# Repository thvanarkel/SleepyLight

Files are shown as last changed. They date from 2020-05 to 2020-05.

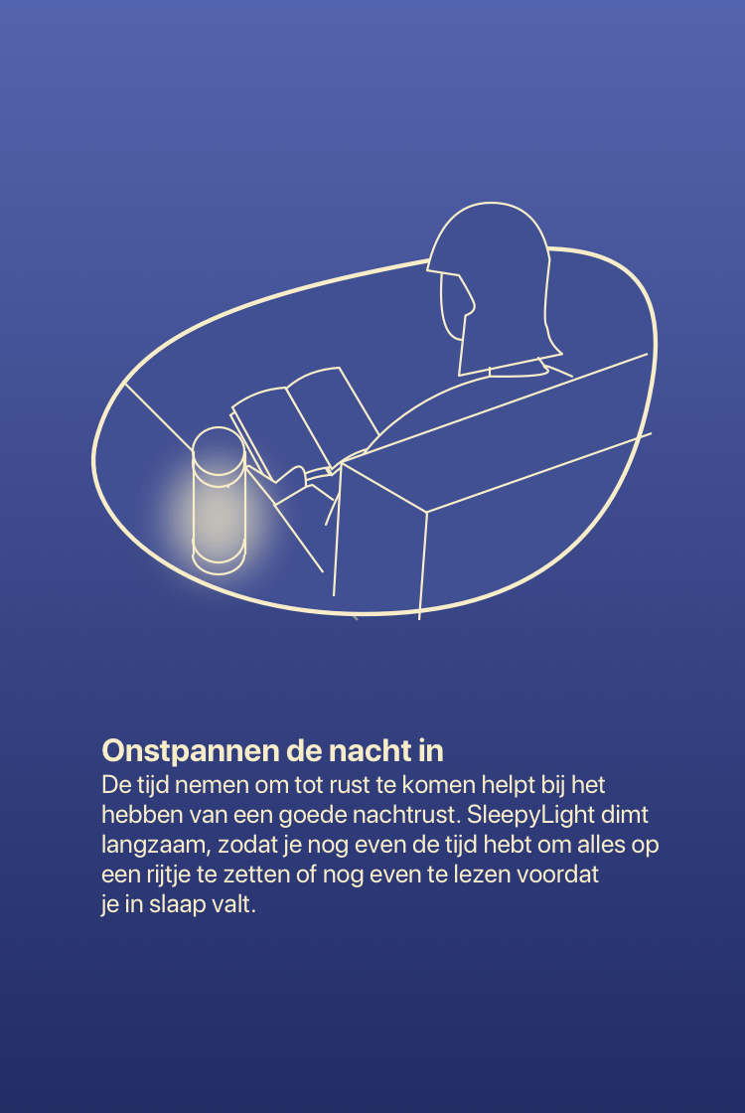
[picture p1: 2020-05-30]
Software/sleepy-config/src/images/flow03.png

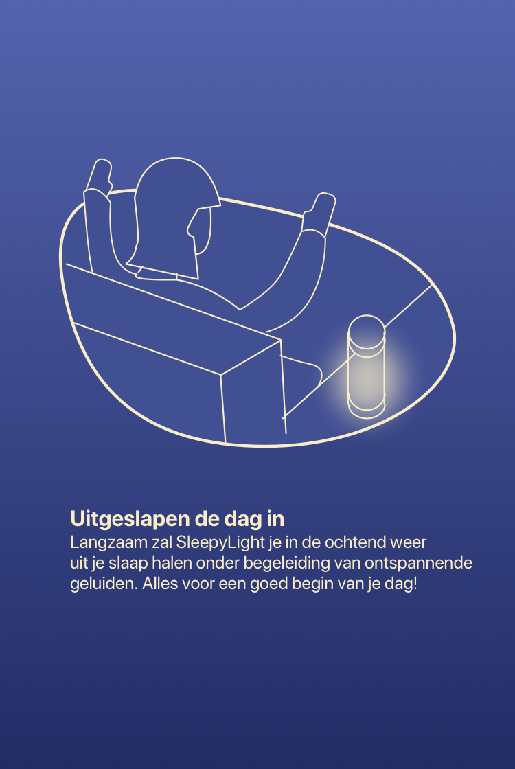
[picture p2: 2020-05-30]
Software/sleepy-config/src/images/flow04.png

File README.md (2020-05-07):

# SleepyLight
Prototype of an interactive SleepyLight. Designed and built for use in the [data-informed-design-experiments](https://github.com/thvanarkel/data-informed-design-experiments) study.

## How to build your own
1. ...
x. Add an arduino_secrets.h file with the following template

```
#define SECRET_SSID ""
#define SECRET_PASS ""
```

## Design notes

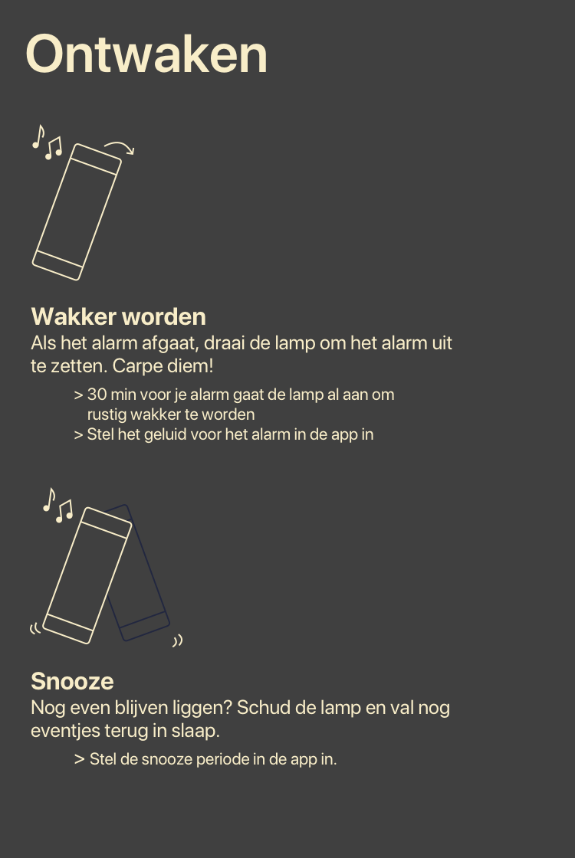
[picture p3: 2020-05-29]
Software/sleepy-config/src/images/help03.png

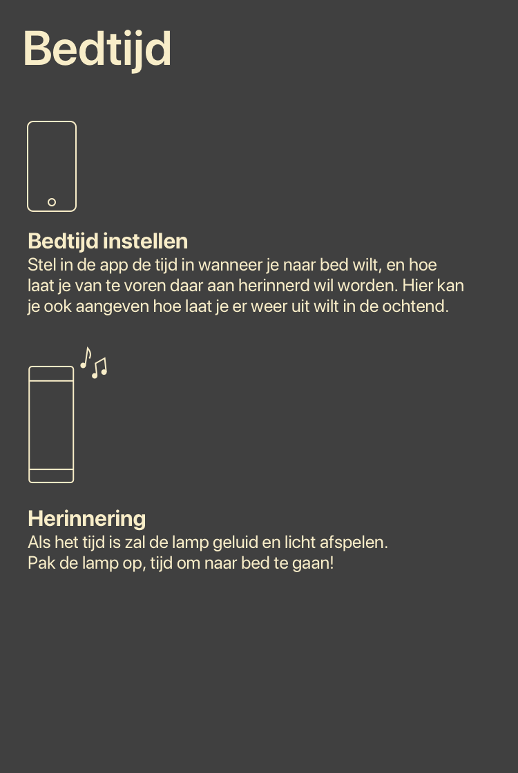
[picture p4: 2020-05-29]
Software/sleepy-config/src/images/help01.png

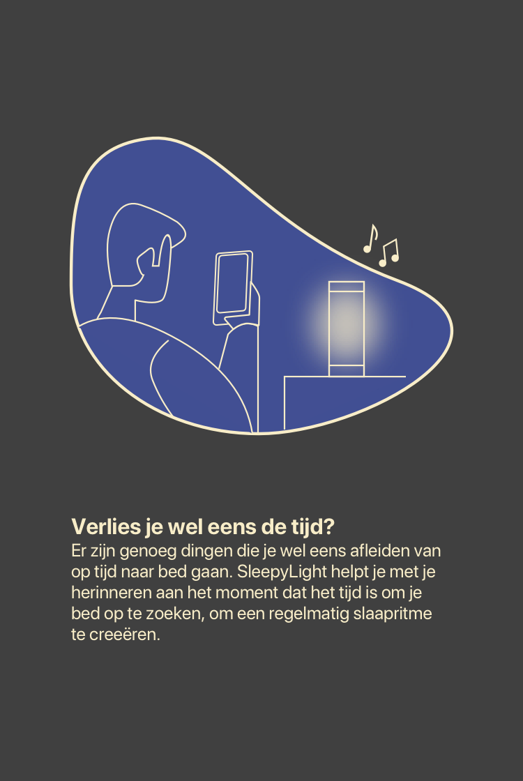
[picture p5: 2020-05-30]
Software/sleepy-config/src/images/flow02.png

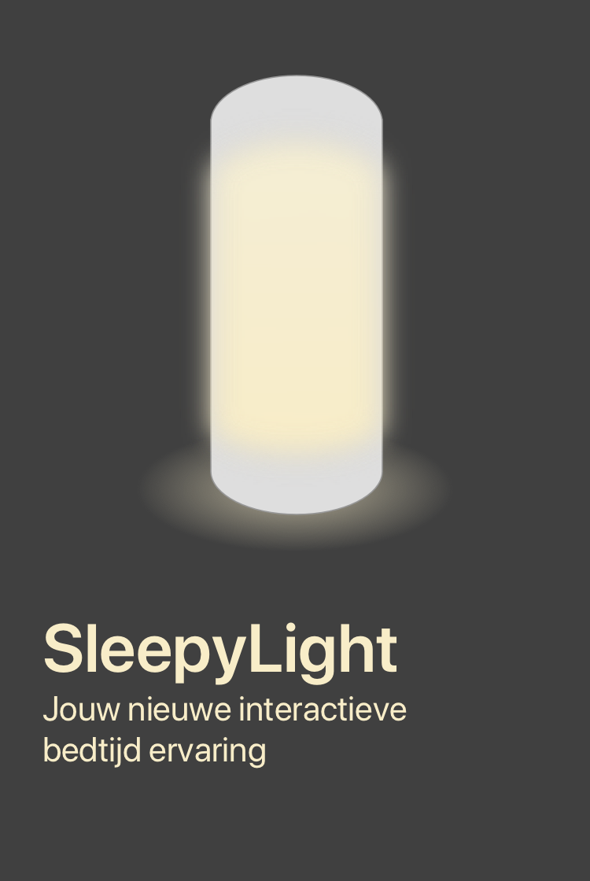
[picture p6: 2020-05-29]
Software/sleepy-config/src/images/flow01.png

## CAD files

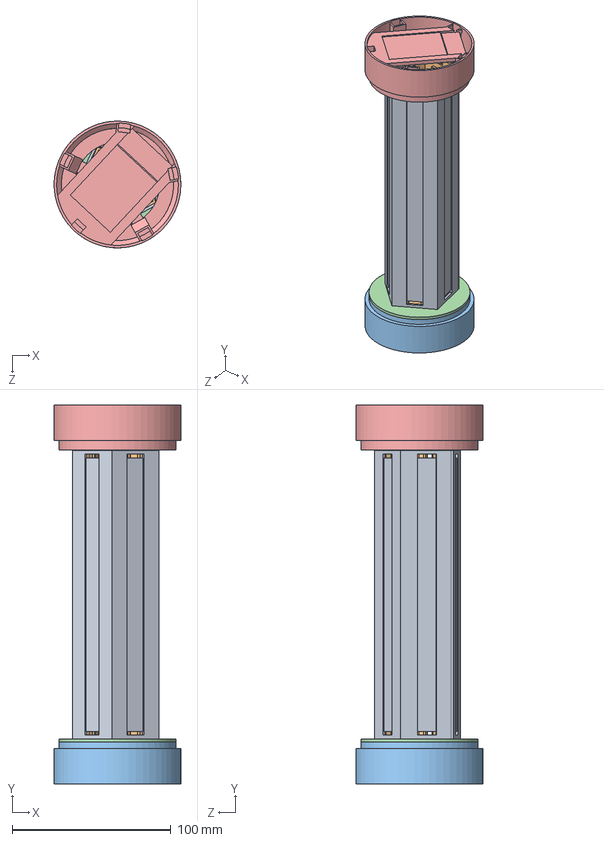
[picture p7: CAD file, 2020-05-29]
Hardware/Lamp.SLDASM
80.0 x 239.0 x 80.0 mm
LED ring
Core
Base
Core connector
Top

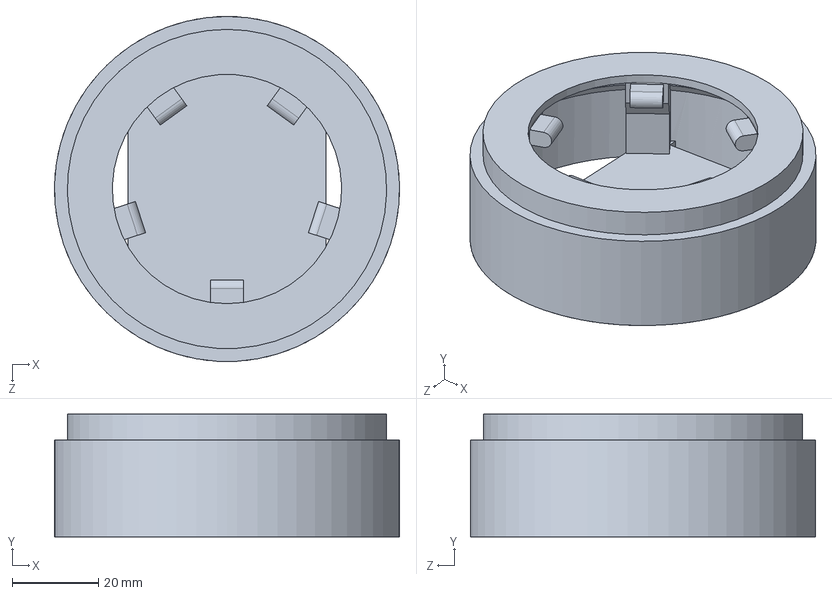
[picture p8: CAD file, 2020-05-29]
Hardware/Top.SLDPRT
80.0 x 28.5 x 80.0 mm

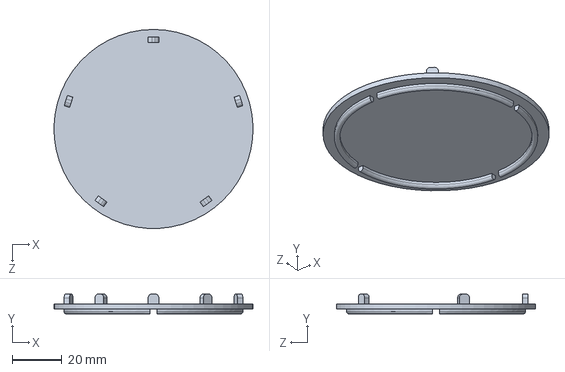
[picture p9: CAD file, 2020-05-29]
Hardware/Top Cap.SLDPRT
80.0 x 8.00 x 80.0 mm

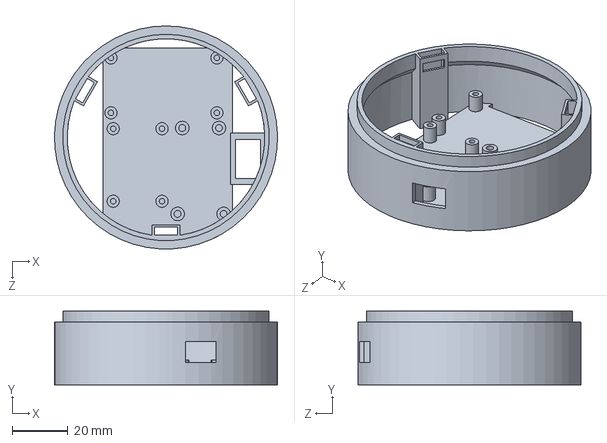
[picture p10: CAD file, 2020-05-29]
Hardware/Base power hole.SLDPRT
80.0 x 26.5 x 80.0 mm

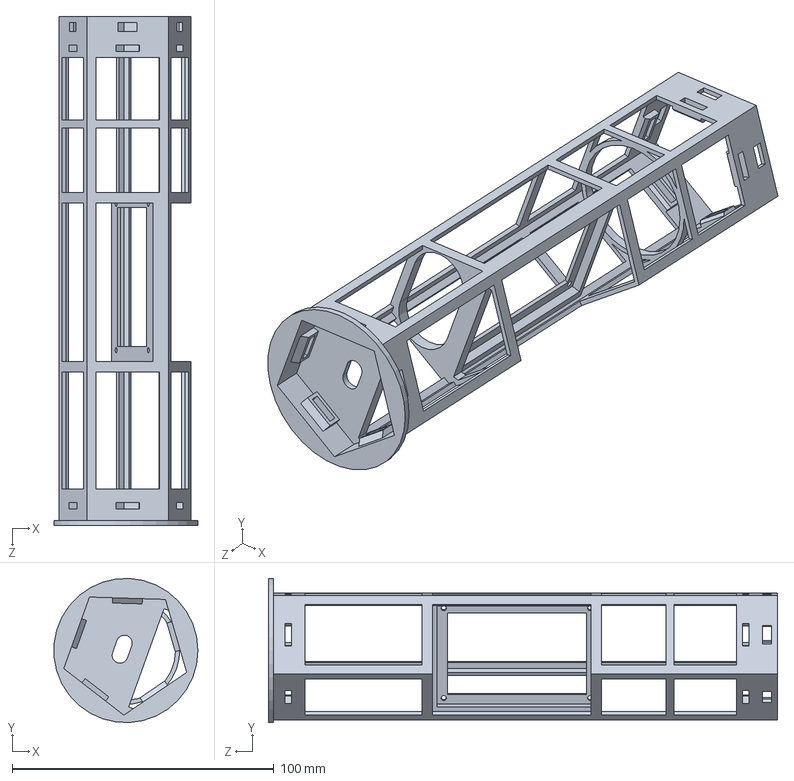
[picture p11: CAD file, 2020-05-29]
Hardware/Core.SLDPRT
55.0 x 55.1 x 194.6 mm

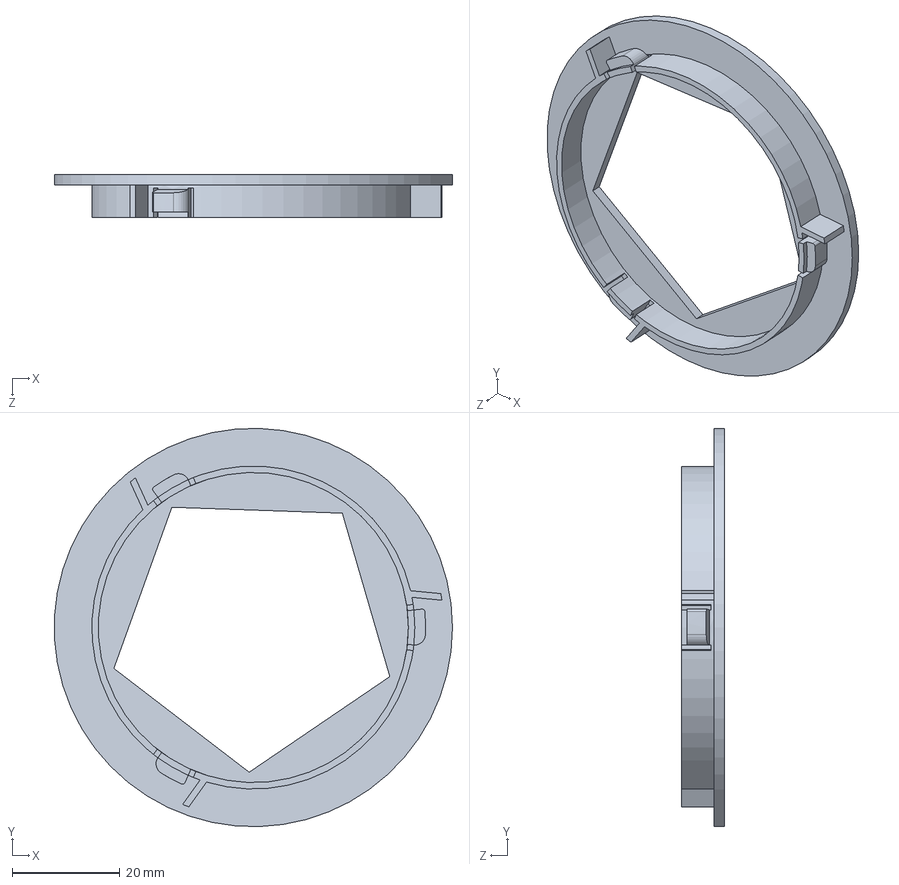
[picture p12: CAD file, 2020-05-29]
Hardware/Core connector.SLDPRT
73.9 x 74.0 x 8.00 mm

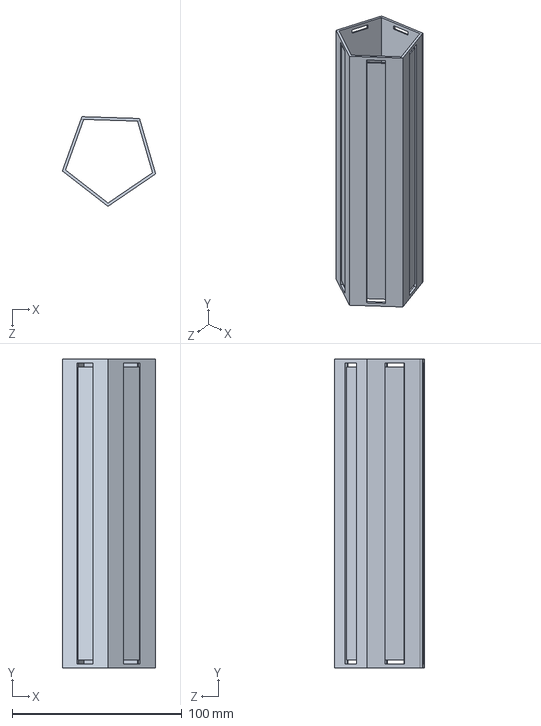
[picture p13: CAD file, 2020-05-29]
Hardware/LED ring.SLDPRT
55.0 x 182.0 x 52.8 mm

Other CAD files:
Hardware/Cap.SLDPRT
Hardware/Base.SLDPRT
Hardware/Base power hole.STL
Hardware/Base.STL
Hardware/Cap.STL
Hardware/Core connector.STL
Hardware/Core.STL
Hardware/LED ring.STL
Hardware/Top Cap.STL
Hardware/Top.STL

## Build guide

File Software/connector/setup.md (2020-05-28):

# Setup

## Requirements
- Raspberry Pi (+ SD card) with Raspbian installed
- USB drive (formatted in exFAT, named 'collector##')

## a. Configuration
1. Flash the SD card with the latest version of Raspbian (through for instance Etcher)
2. Setup the Raspberry Pi (language/timezone/password/update etc.)
3. Change hostname (in RPi Configuration > System) to 'collector##'
4. Enable SSH mode (in RPi Configuration > Interfaces)
5. Update Nodejs
```
$ sudo su
$ curl -sL https://deb.nodesource.com/setup_13.x | bash -
$ apt-get install -y nodejs
```
6. Install exFAT utils
```
$ sudo apt-get install exfat-fuse exfat-utils
```
7. Insert the USB stick (formatted in exFAT, named the same as in step 3: 'collector##')

## b. MQTT server
8. Install Mosquitto
```
$ sudo apt install -y mosquitto mosquitto-clients
$ sudo systemctl enable mosquitto.service
```
9. Configure the mosquitto broker by adding the following to `/etc/mosquitto/conf.d/mosquitto.conf`
```
password_file /etc/mosquitto/passwd
allow_anonymous false
```
10. Add the password file
`$ sudo mosquitto_passwd -c /etc/mosquitto/passwd <user_name>`
11. Restart the mosquitto broker
`$ sudo systemctl restart mosquitto`

## c. Collector script
12. Clone the repository
```
$ git clone https://github.com/thvanarkel/data-informed-design-experiments
```
13. Change to the collector directory, install and add the `.env` file
```
$ cd data-informed-design-experiments/collector
$ npm install
$ touch .env
$ nano .env
```
and add the following:
```
USERN={broker-username}
PASSWORD={broker-password}
HOST={InfluxDB-host-url}
TOKEN={InfluxDB-token}
ORG={InfluxDB-organisation}
BUCKET={InfluxDB-bucket-name}
```
14. Install pm2 and run the collector script on startup
```
$ sudo npm install -g pm2
$ cd /home/pi/Documents/data-informed-design-experiments/collector
$ pm2 start collector.js
$ pm2 startup
$ pm2 save
```

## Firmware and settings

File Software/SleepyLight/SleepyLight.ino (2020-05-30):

#include <WiFiNINA.h>
#include <ArduinoOTA.h>
#include "Lamp.h"
#include <MQTT.h>
#include <SD.h>
#include <SDConfigCommand.h>
#include <ArduinoSound.h>
#include <Arduino_LSM6DS3.h>
#include "SensorFusion.h"

#include <Wire.h>
#include "ds3231.h"
#include "RTClib.h"

#include "arduino_secrets.h">
char ssid[] = SECRET_SSID;
char pass[] = SECRET_PASS;

int status = WL_IDLE_STATUS;

#define LED_TYPE WS2812
#define DATA_PIN 6
#define NUM_LEDS 50

bool turnedOn = false;

WiFiClient net;
MQTTClient client;

RTC_DS3231 rtc;

//char bedtimeDays[8] = "0111110";
//char wakeupDays[8] = "0111110";
//String bedtimeAlarm;
//String wakeupAlarm;

Lamp lamp(5, 10);
unsigned long lastUpdate;

uint8_t sleep_period = 1;
unsigned long prev = 5000, interval = 1000;


struct Config {
  String key;
  String value;
};


#define NUM_CONFIGS 10

Config defaultConfig[NUM_CONFIGS] = {
  {"bedtimedays", "000000"},
  {"wakeupdays", "000000"},
  {"wakeupalarm", "8:00:00"},
  {"bedtimealarm", "23:00:00"},
  {"awakeningtime", "30"},
  {"unwinddecay", "30"},
  {"slumberdecay", "30"},
  {"snooze", "8"},
  {"currentsound", "3"},
  {"bedtimereminder", "30"}
};

Config configuration[NUM_CONFIGS] = {
  {"bedtimedays", ""},
  {"wakeupdays", ""},
  {"wakeupalarm", ""},
  {"bedtimealarm", ""},
  {"awakeningtime", ""},
  {"unwinddecay", ""},
  {"slumberdecay", ""},
  {"snooze", ""},
  {"currentsound", ""},
  {"bedtimereminder", ""}
};


// State parameters

int slumberIntensity = 65;
//int slumberDecay = 30 * 1000;
int slumberShake = 2500;

//int awakeningPeriod = 1; // in minutes

//int unwindDecay = 30;

//int snoozePeriod = 8; // in minutes


#define SHUTDOWN_PIN 5

struct Sound {
  char filename[14];
  int duration;
};

static Sound sounds[8] = {{"birdsong.wav", 61},
  {"bright.wav", 61},
  {"droplets.wav", 61},
  {"early.wav", 54},
  {"helios.wav", 64},
  {"orbit.wav", 64},
  {"spring.wav", 70},
  {"sunny.wav", 60}
};

int currentSound;
unsigned long startedPlaying;

SDConfigCommand sdcc;
SDWaveFile waveFile;

unsigned long reminded;

Orientation orientation;
Orientation lOrientation;
boolean didTurn;
int nShakes;

enum Movement {
  PICKUP = 0,
  SHAKE = 1,
  TURN = 2
};

enum State {
  LIGHT_IDLE,
  REMINDING,
  UNWINDING,
  SLUMBERING,
  AWAKENING,
  ALARMED
};

State currentState = LIGHT_IDLE;
State lastState;

void setup() {
  // put your setup code here, to run once:
  //  Serial.begin(115200);
  //  Serial.print("connecting");
  while (status != WL_CONNECTED) {
    // Connect to WPA/WPA2 network. Change this line if using open or WEP network:
    status = WiFi.begin(ssid, pass);

    // wait 10 seconds for connection:
    Serial.print(".");
    delay(1000);
  }
  client.begin("broker.shiftr.io", net);
  client.onMessage(messageReceived);
  connect();

  client.publish("/restart", "1");


  // Initialise SD card reader and I2S speaker
  if (!SD.begin()) {
    client.publish("/error", "SD initialization failed");
    //    return;
  }

//  SD.remove("setting.cfg"); // Delete configuration file
  // check config
  loadConfig();

  // Initialise RTC
  Wire.begin();
  if (!rtc.begin()) {
    client.publish("/error", "Couldn't find RTC");
  }
  if (rtc.lostPower()) {
    client.publish("/error", "RTC lost power, let's set the time!");
    rtc.adjust(DateTime(F(__DATE__), F(__TIME__)));
  }

  setAlarm(getConfig("wakeupalarm"), true);
  setAlarm(getConfig("bedtimealarm"), false);

  currentSound = getConfig("currentsound").toInt();
  waveFile = SDWaveFile(sounds[currentSound].filename);
  if (!waveFile) {
    client.publish("/error", "wave file invalid");
  }
  AudioOutI2S.volume(60);
  if (!AudioOutI2S.canPlay(waveFile)) {
    client.publish("/error", "unable to play wave file using I2S!");
  }

  // Initialise shutdown pin speaker
  pinMode(SHUTDOWN_PIN, OUTPUT);
  digitalWrite(SHUTDOWN_PIN, LOW);

  if (!IMU.begin()) {
    Serial.println("Failed to initialize IMU!");
  }

  ArduinoOTA.begin(WiFi.localIP(), "SleepyLight", OTA_PASSWORD, InternalStorage);

  updateOrientation();
  // set the initial orientation
  orientation = getOrientation();
  lamp.orientation = orientation;
  client.publish("/orientation", String(orientation));

  client.publish("/state", String(currentState));
  lastState = currentState;
}


int cIndex = 0;

void loadConfig() {
  Serial.println("Creating example.txt...");

  File myFile;

  if (!SD.exists("setting.cfg")) {
    Serial.println("file does not exist");
    myFile = SD.open("setting.cfg", FILE_WRITE);
    writeDefaultConfig(myFile);
    myFile.close();
  }
  // Load the configuration
  while ( !(sdcc.set("setting.cfg", 4, processCmd)) ) {}

  sdcc.readConfig();

}

void writeDefaultConfig(File file) {
  for (int i = 0; i < NUM_CONFIGS; i++) {
    Config c = defaultConfig[i];
    file.print(c.key);
    file.print("=");
    file.println(c.value);
  }
}

void setConfig(String key, String value) {
  for (int i = 0; i < NUM_CONFIGS; i++) {
    Config c = configuration[i];
    if (c.key.equals(key)) {
      c.value = value;
      configuration[i] = c;
      sdcc.writeConfig(key, value);
    }
  }
}

String getConfig(String key) {
  Serial.println(key);
  for (int i = 0; i < NUM_CONFIGS; i++) {
    Config c = configuration[i];
    if (c.key.equals(key)) {
      return c.value;
    }
  }
}

void processCmd() {
  // This function will run every time there is a command
  // Maybe check the key?
  String k = sdcc.getCmdS();
  String v = sdcc.getValueS();

  if (cIndex < NUM_CONFIGS) {
    configuration[cIndex].key = k;
    configuration[cIndex].value = v;
    cIndex++;
  }

}


void connect() {
  Serial.print("checking wifi...");
  while (WiFi.status() != WL_CONNECTED) {
    status = WiFi.begin(ssid, pass);
    Serial.print(".");
    delay(1000);
  }
  Serial.print("\nconnecting...");
  while (!client.connect("SleepyLight", USERNAME, PASSWORD)) {
    Serial.print(".");
    delay(1000);
  }
  Serial.println("\nconnected!");

  client.subscribe("/turnedOn");
  client.subscribe("/wakeup/#");
  client.subscribe("/bedtime/#");
  client.subscribe("/awakeTime");
  client.subscribe("/unwindTime");
  client.subscribe("/slumberTime");
  client.subscribe("/sound");
  client.subscribe("/snooze");
  //  client.subscribe("/ledLevel");
}

boolean disconnected = false;

void loop() {
  //  watchdog.clear();
  ArduinoOTA.poll();
  lamp.tick();
  //  Serial.println(lamp.level);

  if (!client.connected()) {
    connect();
  }
  client.loop();


  if (!AudioOutI2S.isPlaying()) {
    // playback has stopped
    digitalWrite(SHUTDOWN_PIN, LOW);
    // Doing this during I2S outputting sound willl drop connection
  }

  if (currentState != lastState) {
    client.publish("/state", String(currentState));
    lastState = currentState;
  }
  if (orientation != lOrientation) {
    client.publish("/orientation", String(orientation));
    lOrientation = orientation;
  }

  if (millis() - lastUpdate > 1000) {
    client.publish("/ledLevel", String(lamp.level));
    lastUpdate = millis();
  }

  updateOrientation();
  detectMovement();
  lamp.orientation = orientation;

  //  unsigned long n = millis();
  //  if ((n - prev > interval)) {
  //    DateTime now = rtc.now();
  //    publishDate("/time", now);
  //    prev = n;
  //  }

  updateStateMachine();

  delay(15);
}

void updateStateMachine() {
  switch (currentState) {
    case LIGHT_IDLE:

      // Check if the lamp is turned
      if (detectTurn(orientation)) {
        lamp.orientation = orientation;
        lamp.turnOn(2000);
        currentState = UNWINDING;
      }

      // Check if the wake-up alarm has fired
      if (rtc.alarmFired(1)) {
        rtc.clearAlarm(1);
        DateTime now = rtc.now();
        DateTime future(now + TimeSpan(0, 0, getConfig("awakeningtime").toInt(), 0));
        rtc.setAlarm1(future, DS3231_A1_Hour);
        lamp.turnOn(getConfig("awakeningtime").toInt() * 60 * 1000);
        currentState = AWAKENING;
      }
      if (rtc.alarmFired(2)) {
        rtc.clearAlarm(2);
        
        setSound(5);
        playSound();
        reminded = millis();
        currentState = REMINDING;
      }

      if (!lamp.inAnimation() && nShakes > 3) {
        lamp.setLevel(slumberIntensity, 1500);
        nShakes = 0;
        currentState = SLUMBERING;
      }

      break;

    case REMINDING:
      lamp.mode = MOVING;
      breakOffSound(8);
      if (nShakes > 0 || millis() - reminded > 60000) {
        lamp.mode = SOLID;
        stopSound();
        currentSound = getConfig("currentsound").toInt();
        currentState = LIGHT_IDLE;
        nextAlarm(false);
      }
      break;

    case UNWINDING:        
      if (!lamp.inAnimation()) {
        if (lamp.level >= 1023) {
          lamp.turnOff(getConfig("unwinddecay").toInt() * 60 * 1000);
        } else if (lamp.level <= 0) {
          currentState = LIGHT_IDLE;
        }
      }
      if (nShakes > 3) {
        nShakes = 0;
        lamp.changeTime((-60 * 1000));
      }
      break;

    case AWAKENING:
      if (rtc.alarmFired(1)) {
        rtc.clearAlarm(1);
        playSound();
        nShakes = 0;
        currentState = ALARMED;
      }
      break;

    case ALARMED:
      if (!AudioOutI2S.isPlaying()) {
        // playback has stopped
        playSound();
      } else {
        breakOffSound(8);
      }
      if (nShakes > 3) {
        stopSound();
        nShakes = 0;
        DateTime now = rtc.now();
        DateTime future(now + TimeSpan(0, 0, getConfig("snooze").toInt(), 0)); // TODO: fix the times
        rtc.setAlarm1(future, DS3231_A1_Hour);
        currentState = AWAKENING;
        break;
      }
      if (detectTurn(orientation)) {
        stopSound();
        lamp.orientation = orientation;
        lamp.turnOff(2000);
        nextAlarm(true);
        currentState = LIGHT_IDLE;
        nShakes = 0;
        break;
      }
      break;

    case SLUMBERING:
      if (!lamp.inAnimation()) {
        if (lamp.level >= slumberIntensity) {
          lamp.turnOff(getConfig("slumberdecay").toInt() * 1000);
        } else {
          currentState = LIGHT_IDLE;
        }
      }
      if (nShakes > 2) {
        lamp.setLevel(slumberIntensity, 500);
        nShakes = 0;
      }
      if (detectTurn(orientation)) {
        lamp.orientation = orientation;
        lamp.turnOn(2000);
        currentState = UNWINDING;
      }
      break;
  }
}

String getValue(String data, char separator, int index)
{
  int found = 0;
  int strIndex[] = {0, -1};
  int maxIndex = data.length() - 1;

  for (int i = 0; i <= maxIndex && found <= index; i++) {
    if (data.charAt(i) == separator || i == maxIndex) {
      found++;
      strIndex[0] = strIndex[1] + 1;
      strIndex[1] = (i == maxIndex) ? i + 1 : i;
    }
  }
  return found > index ? data.substring(strIndex[0], strIndex[1]) : "";
}

void setAlarm(String str, boolean wakeup) {
  //(year, month, day, hour, minute, second)

  int alarmIndex = wakeup ? 1 : 2;
  rtc.clearAlarm(alarmIndex);
  DateTime now = rtc.now();
  DateTime a(now.year(), now.month(), now.day(), getValue(str, ':', 0).toInt(), getValue(str, ':', 1).toInt(), 0);
  if (now < a) {
    // Still do the alarm today
    char theDay;
    if (wakeup) {
      char wd[8];
      getConfig("wakeupdays").toCharArray(wd, 8);
      theDay = wd[now.dayOfTheWeek()];
    } else {
      char bd[8];
      getConfig("bedtimedays").toCharArray(bd, 8);
      theDay = bd[now.dayOfTheWeek()];
    }
    if (theDay == '1') {
      DateTime future;
      if (wakeup) {
        int o = getConfig("awakeningtime").toInt();
        future = a - TimeSpan(0, 0, o, 0);
        rtc.setAlarm1(future, DS3231_A1_Hour);
        publishDate("/wakeup/date", future);
      } else {
        future = a - TimeSpan(0, 0, getConfig("bedtimereminder").toInt(), 0);
        rtc.setAlarm2(future, DS3231_A2_Hour);
        publishDate("/bedtime/date", future);
      }
    } else {
      nextAlarm(wakeup);
    }
  } else {
    // Schedule next alarm
    nextAlarm(wakeup);
  }
}


void nextAlarm(boolean wakeup)
{
  //  DateTime future(now + TimeSpan(0, 0, 1, 0));
  //
  //  rtc.setAlarm1(future, DS3231_A1_Minute);
  DateTime now = rtc.now();
  String str = wakeup ? getConfig("wakeupalarm") : getConfig("bedtimealarm");
  DateTime a(now.year(), now.month(), now.day(), getValue(str, ':', 0).toInt(), getValue(str, ':', 1).toInt(), 0);
  boolean foundNext = false;
  int i = 1;
  while (!foundNext) {
    int index = now.dayOfTheWeek() + i > 6 ? now.dayOfTheWeek() + i - 7 : now.dayOfTheWeek() + i;
    char wd[8];
    getConfig("wakeupdays").toCharArray(wd, 8);
    char d = wakeup ? wd[index] : wd[index];
    if (d != '1') {
      i++;
    } else {
      foundNext = true;
      DateTime n = a + TimeSpan(i, 0, 0, 0);
      DateTime future;
      if (wakeup) {
        future = n - TimeSpan(0, 0, getConfig("awakeningtime").toInt(), 0);
        rtc.setAlarm1(future, DS3231_A1_Date);
        publishDate("/wakeup/date", future);
      } else {
        future = n - TimeSpan(0, 0, getConfig("bedtimereminder").toInt(), 0);
        rtc.setAlarm2(future, DS3231_A2_Date);
        publishDate("/bedtime/date", future);
      }
    }
    if (i > 7) {
      if (wakeup) {
        int alarmIndex = wakeup ? 1 : 2;
        rtc.clearAlarm(alarmIndex);
      }
      break; // No dates selected
    }
  }
}

void publishDate(String topic, DateTime date) {
  String time = String(date.day(), DEC) + "." + String(date.month(), DEC) + "." + String(date.year(), DEC) + ": " + String(date.hour(), DEC) + ":" + String(date.minute(), DEC) + ":" + String(date.second(), DEC);
  //    //         // snprintf(buff, BUFF_MAX, "%d.%02d.%02d %02d:%02d:%02d", now.year, now.month, now.mday, now.hour, now.min, now.sec);
  client.publish(topic, time);
}

void messageReceived(String &topic, String &payload) {
  Serial.println(topic);
  Serial.println(payload);
  if (payload.equals("true") && lamp.level <= 0) {
    lamp.turnOn(2000);
  } else if (payload.equals("false") && lamp.level >= 1023) {
    lamp.turnOff(2000);
  } else if (topic.equals("/wakeup/alarm")) {
    setConfig("wakeupalarm", payload);
    setAlarm(payload, true);
  } else if (topic.equals("/wakeup/days")) {
    setConfig("wakeupdays", payload);
  } else if (topic.equals("/bedtime/alarm")) {
    setConfig("bedtimealarm", payload);
    setAlarm(payload, false);
  } else if (topic.equals("/bedtime/days")) {
    setConfig("bedtimedays", payload);
  } else if (topic.equals("/bedtime/reminder")) {
    setConfig("bedtimereminder", payload);
    setAlarm(getConfig("bedtimealarm"), false);
  } else if (topic.equals("/awakeTime")) {
    setConfig("awakeningtime", payload);
    setAlarm(getConfig("wakeupalarm"), true);
  } else if (topic.equals("/unwindTime")) {
    setConfig("unwinddecay", payload);
  } else if (topic.equals("/slumberTime")) {
    setConfig("slumberdecay", payload);
  } else if (topic.equals("/snooze")) {
    setConfig("snooze", payload);
  } else if (topic.equals("/sound")) {
    setConfig("currentsound", payload);
    setSound(payload.toInt());
  }
}

void setSound(int index) {
  currentSound = index;
  waveFile = SDWaveFile(sounds[currentSound].filename);
  if (!waveFile) {
    client.publish("/error", "wave file invalid");
  }
}

void playSound() {
  digitalWrite(SHUTDOWN_PIN, HIGH);
  AudioOutI2S.play(waveFile);
  startedPlaying = millis();
}

void breakOffSound(int cutoff) {
  if (millis() - startedPlaying > ((sounds[currentSound].duration - cutoff) * 1000)) {
    stopSound();
  }
}

void stopSound() {
  digitalWrite(SHUTDOWN_PIN, LOW);
  AudioOutI2S.stop();
}

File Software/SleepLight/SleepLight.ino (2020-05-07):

#include <WiFiNINA.h>

#include "arduino_secrets.h">
char ssid[] = SECRET_SSID;
char pass[] = SECRET_PASS;

int status = WL_IDLE_STATUS;

enum State {
  LIGHT_IDLE,
  UNWINDING,
  SLEEPING,
  AWAKENING
};

State currentState = LIGHT_IDLE;

void setup() {
  // put your setup code here, to run once:
  Serial.begin(115200);
  Serial.print("connecting");
  while (status != WL_CONNECTED) {
    // Connect to WPA/WPA2 network. Change this line if using open or WEP network:
    status = WiFi.begin(ssid, pass);
    // wait 10 seconds for connection:
    Serial.print(".");
    delay(1000);
  }
  printWiFiStatus();

}

void loop() {
  // put your main code here, to run repeatedly:
  Serial.println();
  delay(1000);
  updateStateMachine();
}

void updateStateMachine() {
  switch(currentState) {
    case LIGHT_IDLE:
      break;

    case UNWINDING:
      break;

    case SLEEPING:
      break;

    case AWAKENING:
      break;
  }
}

void printWiFiStatus() {
  // print the SSID of the network you're attached to:
  Serial.print("SSID: ");
  Serial.println(WiFi.SSID());

  // print your WiFi shield's IP address:
  IPAddress ip = WiFi.localIP();
  Serial.print("IP Address: ");
  Serial.println(ip);

  // print the received signal strength:
  long rssi = WiFi.RSSI();
  Serial.print("signal strength (RSSI):");
  Serial.print(rssi);
  Serial.println(" dBm");
}

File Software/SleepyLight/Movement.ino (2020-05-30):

SF fusion;

float gx, gy, gz, ax, ay, az;
float pitch, roll, yaw;
float deltat;

float pPitch, pRoll;

#define TURN_THRESHOLD 10

unsigned long last;

boolean detectTurn(Orientation lastOrientation) {
  Orientation currentOrientation = getOrientation();
  orientation = currentOrientation;
  return (currentOrientation != lastOrientation);
}

Orientation getOrientation() {
  if (pitch < 0) {
    return UPWARD;
  } else if (pitch > 0) {
    return DOWNWARD;
  }
}

unsigned long shakeDebounce;
unsigned long lastShake;

#define SHAKE_SENSITIVITY 4
#define SHAKE_RESET 2000

void detectMovement() {
  if (roll - pRoll > SHAKE_SENSITIVITY || pitch - pPitch > SHAKE_SENSITIVITY) {
    if (millis() - shakeDebounce > 75) {
      nShakes++;
      lastShake = millis();
      shakeDebounce = millis();
      client.publish("/shakes", String(nShakes));
    }

//    delay(75);
  }
  if (millis() - lastShake > SHAKE_RESET) {
    nShakes = 0;
  }
}

void updateOrientation() {
  pPitch = pitch;
  pRoll = roll;



  if (IMU.accelerationAvailable() && IMU.gyroscopeAvailable()) {
    IMU.readAcceleration(ax, ay, az);
    IMU.readGyroscope(gx, gy, gz);
    float gyroScale = 0.097656f / 4.5;
    gx = gx * gyroScale;
    gy = gy * gyroScale;
    gz = gz * gyroScale;
  }
  deltat = fusion.deltatUpdate(); //this have to be done before calling the fusion update
  fusion.MahonyUpdate(gx, gy, gz, ax, ay, az, deltat);

  pitch = fusion.getPitch();
  roll = fusion.getRoll();
  yaw = fusion.getYaw();

//  Serial.print(pitch - pPitch);
//  Serial.print(" ");
//  Serial.println(roll - pRoll);
}

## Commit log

2020-01-13 Revert "Integrated RTC example"
    This reverts commit 2168cc7fa62f7af98becc970e2f8e2d5cebf8f11.
    [SleepLight.ino]
2020-01-13 Revert "Revert "Integrated RTC example""
    This reverts commit eab6cdbe1b08dd9fbc8d7f3d22a7ac17c9c19dbb.
    [SleepLight.ino]
2020-01-14 Added CAD files for initial version of the base
    [Base.SLDPRT, Base.STL]
2020-01-15 Add connection points
    Add the connection points that hook into the base of the lamp
    [Base.SLDPRT, Base.STL]
2020-01-18 Add core model
    [Core.SLDPRT]
2020-01-19 Add grooves for LED strips
    [Core.SLDPRT, Core.STL]
2020-01-19 Add cap on end
    [Core.SLDPRT, Core.STL]
2020-01-19 Rename 'Core' to 'LED ring'
    [Core.SLDPRT, LED ring.SLDPRT, LED ring.STL]
2020-01-20 Change LED ring to spoke version
    [LED ring.SLDPRT]
2020-01-27 Add core and assembly
    [Core.SLDPRT, LED ring.SLDPRT, Lamp.SLDASM]
2020-01-31 Add PCB holder module
    [PCB holder.SLDPRT, PCB holder.STL]
2020-01-31 Update to fit PCB holder
    [Core.SLDPRT, Lamp.SLDASM, PCB holder.SLDPRT]
2020-02-01 Add speaker fixture
    [Core.SLDPRT]
2020-02-01 Add spool fixtures and power board mount
    [Core.SLDPRT, Core.SLDPRT.STL, Spool fixture.sldprt]
2020-02-04 Update Core
    [Core.SLDPRT, Core.STL, Lamp.SLDASM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]
2020-02-24 Remove connection amplifier
    Amplifier can be soldered to the perfboard, so no additional connection is required.
    [Core.SLDPRT]
2020-02-24 Remove spacings for slots
    [Core.SLDPRT]
2020-02-24 Remove holes for LED connectors
    [Core.SLDPRT]
2020-04-09 Create base
    [Base.SLDPRT, Base.STL, Core.SLDPRT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]
2020-04-12 Change Base
    [Base.SLDPRT, Base.STL, Core.SLDPRT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]
2020-04-18 Update base
    [Base - Copy.SLDPRT, Base.SLDPRT, Base.SLDPRT.STL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]
2020-05-07 Add arduino_secrets.h
2020-05-20 Switch to FastLED library
2020-05-22 Fix WiFi dropping during playing I2S sounds
    [Lamp.cpp, SleepyLight.ino]
2020-05-25 Fix audio dropping internet connection
    [SleepyLight.ino]
2020-05-26 Initial movement detection implementation
    + removed the token from the sketch to arduino_secrets.h
2020-05-26 Finetune LED behaviour
2020-05-28 Add connector script
2020-05-28 Final embodiment
    [Base - Copy.SLDPRT, Base power hole.STL, Base.SLDPRT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]
2020-05-29 Fix sound message not always being sent
    [SleepyLight.ino]
2020-05-29 Remove old files
    [Base power hole.SLDPRT, Core.SLDPRT.STL, PCB holder.SLDPRT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]
2020-05-29 Fix sound not selected after bedtime reminder
    [SleepyLight.ino]
